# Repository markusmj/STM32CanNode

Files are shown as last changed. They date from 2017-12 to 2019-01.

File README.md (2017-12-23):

# STM32CanNode

Software still highly unstable and updating code all the time. Use at your own risk!!!

Projects goal is to make a simple Can Node which will read 10 analog inputs and send their data to Canbus. Idea is also to design simple connecting PCB where common and cheap STM32F103C8T6 Blue Pill Development Board and MCP2515+TJA1050 Can module can be used to create compact package with Analog/digital ports and Can capabilities.

Some key features of selected hardware:
- Fast SPI bus 18MHz
- 1000kbit/s Can bus
- Fast 12-bit ADC
- 10 analog channels

STM32Duino:
http://www.stm32duino.com/

Used MCP2515 library:
https://github.com/Seeed-Studio/CAN_BUS_Shield

More info on STM32 Development Board Nicknamed Blue Pill:
http://wiki.stm32duino.com/index.php?title=Blue_Pill

MCP 2515 Module used:
https://www.banggood.com/D33-MCP2515-CAN-Bus-Module-TJA1050-Receiver-SPI-Protocol-p-1015302.html

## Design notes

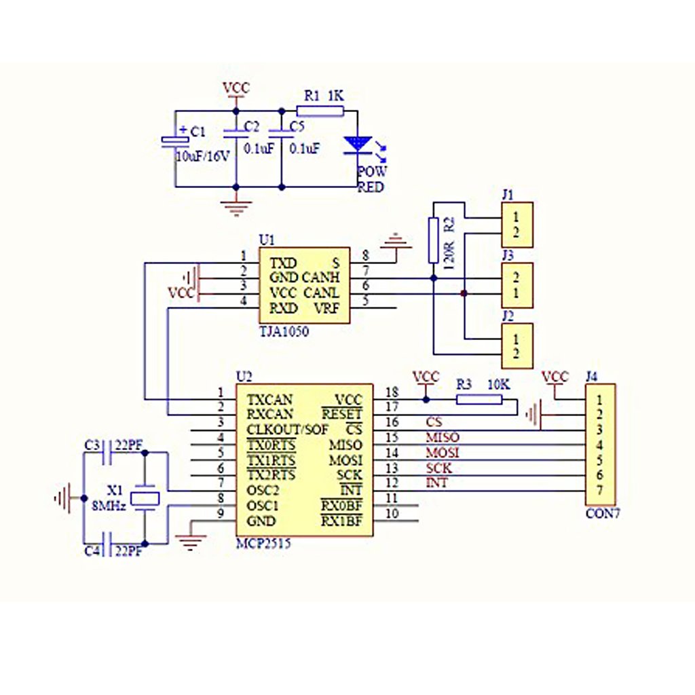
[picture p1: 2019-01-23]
MCP2515Schema/61RsJwa0vkL._SL1024_.jpg

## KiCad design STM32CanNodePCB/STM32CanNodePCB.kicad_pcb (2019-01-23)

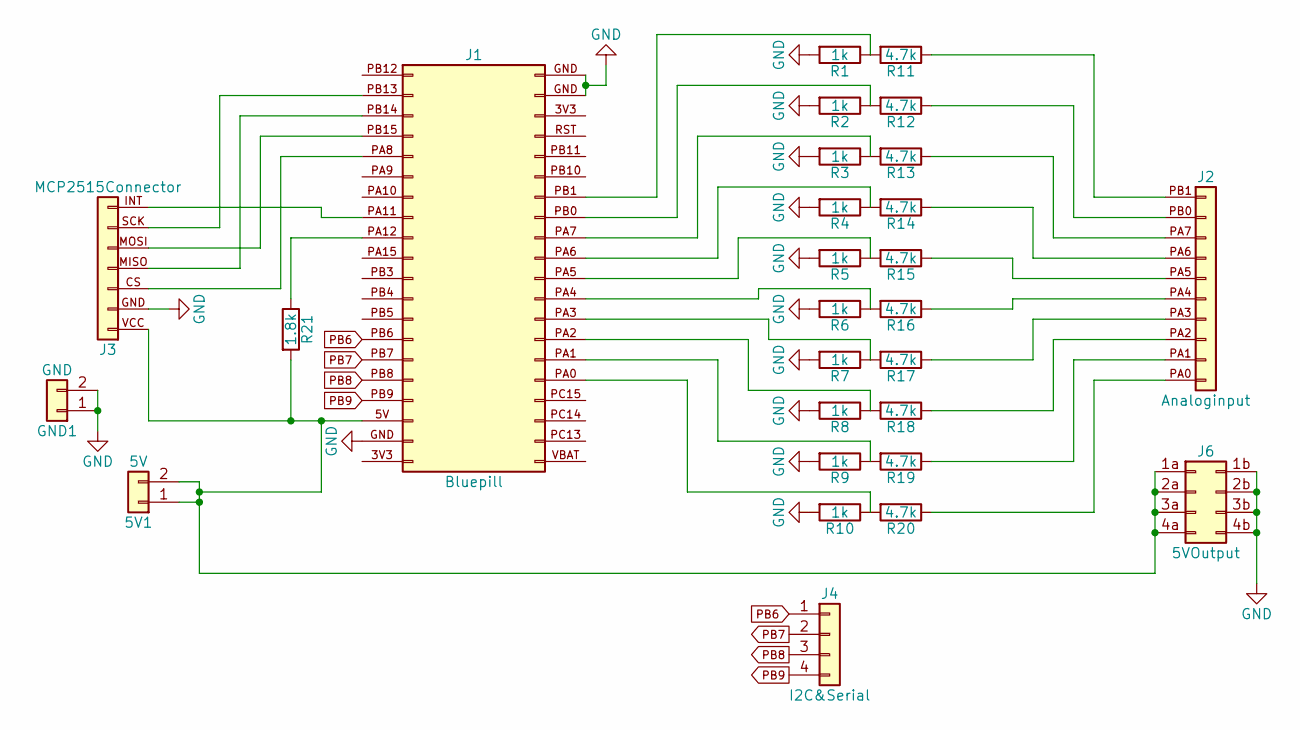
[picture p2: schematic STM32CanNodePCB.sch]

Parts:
5V1: 5V; Pin_Header_Straight_1x02_Pitch2.54mm
GND1: GND; Pin_Header_Straight_1x02_Pitch2.54mm
J1: Bluepill; BluePill
J2: Analoginput
J3: MCP2515Connector
J4: I2C&Serial; Pin_Header_Straight_1x04_Pitch2.54mm
J6: 5VOutput
R1, R2, R3, R4, R5, R6, R7, R8, R9, R10: 1k; R_1206_HandSoldering
R11, R12, R13, R14, R15, R16, R17, R18, R19, R20: 4.7k; R_1206_HandSoldering
R21: 1.8k; R_1206_HandSoldering

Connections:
GND: GND1.1, GND1.2, J1.GND, J3.GND, J6.1b, J6.2b, J6.3b, J6.4b, R1.2, R2.2, R3.2, R4.2, R5.2, R6.2, R7.2, R8.2, R9.2, R10.2
unnamed: 5V1.1, 5V1.2, J1.5V, J3.VCC, J6.1a, J6.2a, J6.3a, J6.4a, R21.2
unnamed: J1.PA0, R10.1, R20.2
unnamed: J1.PA1, R9.1, R19.2
unnamed: J1.PA2, R8.1, R18.2
unnamed: J1.PA3, R7.1, R17.2
unnamed: J1.PA4, R6.1, R16.2
unnamed: J1.PA5, R5.1, R15.2
unnamed: J1.PA6, R4.1, R14.2
unnamed: J1.PA7, R3.1, R13.2
unnamed: J1.PA8, J3.CS
unnamed: J1.PA11, J3.INT
unnamed: J1.PA12, R21.1
unnamed: J1.PB0, R2.1, R12.2
unnamed: J1.PB1, R1.1, R11.2
unnamed: J1.PB13, J3.SCK
unnamed: J1.PB14, J3.MISO
unnamed: J1.PB15, J3.MOSI
unnamed: J2.PA0, R20.1
unnamed: J2.PA1, R19.1
unnamed: J2.PA2, R18.1
unnamed: J2.PA3, R17.1
unnamed: J2.PA4, R16.1
unnamed: J2.PA5, R15.1
unnamed: J2.PA6, R14.1
unnamed: J2.PA7, R13.1
unnamed: J2.PB0, R12.1
unnamed: J2.PB1, R11.1
PB6: J1.PB6, J4.1
PB7: J1.PB7, J4.2
PB8: J1.PB8, J4.3
PB9: J1.PB9, J4.4

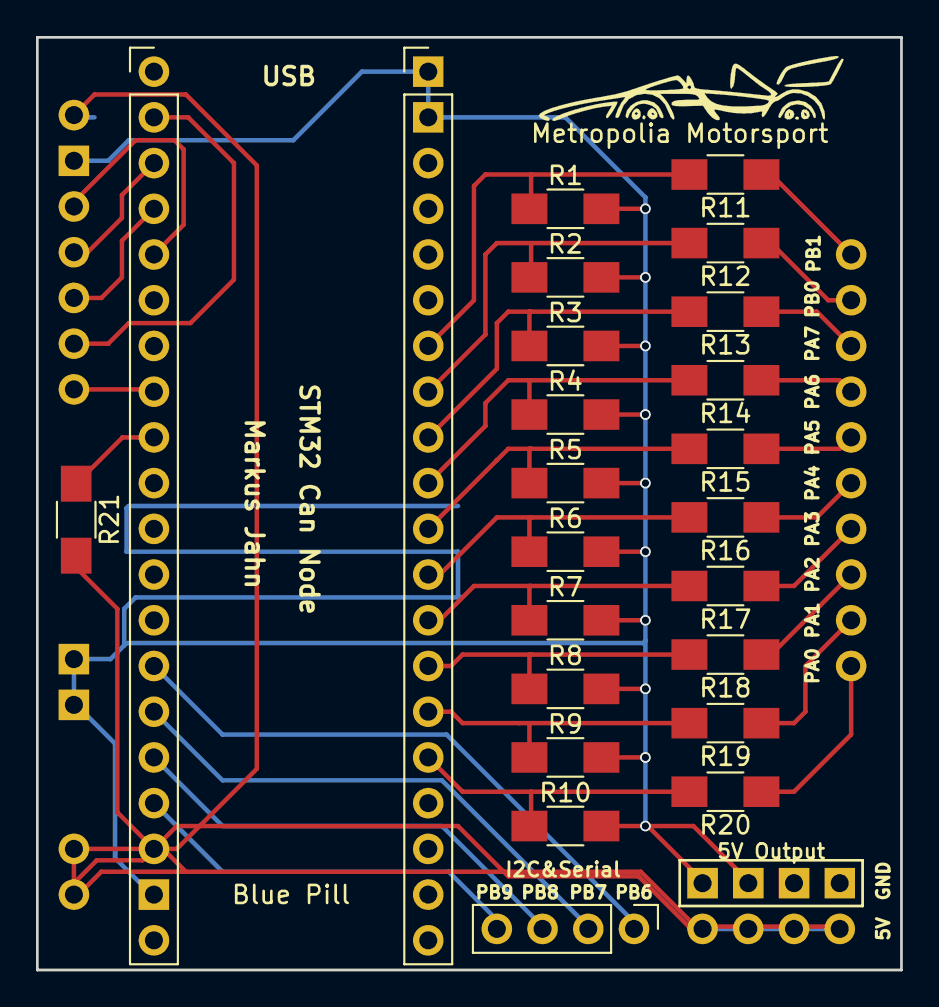
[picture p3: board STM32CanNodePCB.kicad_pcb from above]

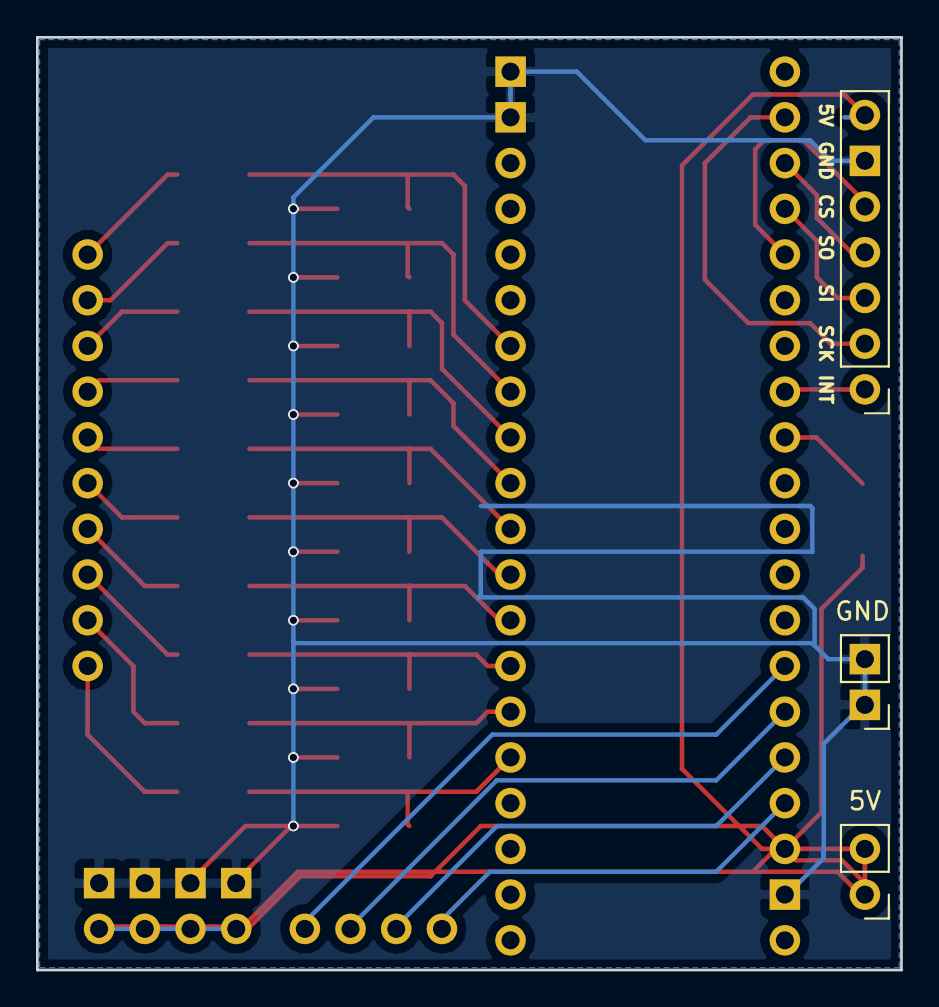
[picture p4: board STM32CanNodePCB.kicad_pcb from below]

Board: 2 copper layers, 48.0 x 51.8 mm, 28 parts (3 on the bottom side), 32 nets.

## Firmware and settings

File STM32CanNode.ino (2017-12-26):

// demo: CAN-BUS Shield, send data
#include <mcp_can.h>
#include <SPI.h>
#include <STM32ADC.h>

/*
 * Pin Connections to MCP2515
 * 
 * PB13 <-> SCK
 * PB14 <-> MISO
 * PB15 <-> MOSI
 * PA8 <-> CS
 * PA11 <-> INT 
 * 5V <-> VCC
 * GND <-> GND
 */

uint8 pins[] = {PA0,PA1,PA2,PA3,PA4,PA5,PA6,PA7,PB0}; //Analog input pins



unsigned char stmp[8] = {0, 0, 0, 0, 0, 0, 0, 0};
unsigned char stmp2[8] = {0, 0, 0, 0, 0, 0, 0, 0};
unsigned char stmp3[8] = {0, 0, 0, 0, 0, 0, 0, 0};

const int SPI_CS_PIN = PA8; //MCP2515 CS pin

const int maxSamples = 9; // 10 Analog inputs
const int avgsamples=5; // How many reads to average for increased accuracy. Max. 15 samples.

//Frequency input data
HardwareTimer pwmtimer(4); //Just for checking
unsigned long freqtime = micros();
unsigned long freq;

// Array for the ADC data
uint16 dataPoints[maxSamples];
uint16 tempdataPoints[maxSamples];


MCP_CAN CAN(SPI_CS_PIN);                                    // Set CS pin

volatile static bool dma1_ch1_Active; //flag for interrupt
STM32ADC NodeADC(ADC1);

void setup()
{

    //PWM write to check frequency reader
    pinMode(PB9,PWM);
    pwmtimer.setPrescaleFactor(1);
    pwmtimer.setPeriod(1000);
    pwmWrite(PB9, 5000);
    
    // Frequency read. Remove/add accordingly to analog inputs.
    pinMode(PB1,INPUT_PULLDOWN);
    attachInterrupt(PB1, interruptFunction, FALLING);
        
    SPI.setModule(2);   //Define SPI to SPI2
    SPI.setClockDivider(SPI_CLOCK_DIV2);   //Define Speed of SPI
    Serial.begin(115200);
    

    while (CAN_OK != CAN.begin(CAN_1000KBPS))              // Init can bus : baudrate = 1000k
    {
        
        Serial.println("CAN BUS Shield init fail");
        Serial.println(" Init CAN BUS Shield again");
        delay(100);
    }
    
    Serial.println("CAN BUS Shield init ok!");

    //calibrate ADC
    NodeADC.calibrate(); 
    NodeADC.setSampleRate(ADC_SMPR_13_5); //sample ratio
    NodeADC.setPins(pins, maxSamples);   //pins to be converted
    NodeADC.setScanMode();               //Set the ADC in Scan Mode
    
}


void loop()
{  
    int Timing = micros();

    for(unsigned int j = 0; j < maxSamples; j++) {tempdataPoints[j] = 0;}  //Zeros to temp variable
    
        for(unsigned int i = 0; i < avgsamples; i++) {                       // --- Read Analog ports 15 times to get average of readings. Remove Lines marked with --- to read faster without averaging
        dma1_ch1_Active = 1;
        NodeADC.setDMA(dataPoints, maxSamples, (DMA_MINC_MODE | DMA_TRNS_CMPLT), DMA1_CH1_Event); 
        NodeADC.startConversion();
        while (dma1_ch1_Active == 1); //wait for DMA to complete.  
              for(unsigned int j = 0; j < maxSamples; j++) {                 // ---
              tempdataPoints[j] = tempdataPoints[j] + dataPoints[j]; // --- Add values to temp variable
              }                                                      // ---
    
        }                                                            // ---

    for(unsigned int i = 0; i < maxSamples; i++) {dataPoints[i] = tempdataPoints [i]/avgsamples;}    // --- Average dataPoints from temp variable.  
    
    unsigned char stmp[8] = {lowByte(dataPoints[0]), highByte(dataPoints[0]), lowByte(dataPoints[1]), highByte(dataPoints[1]), lowByte(dataPoints[2]), highByte(dataPoints[2]), lowByte(dataPoints[3]), highByte(dataPoints[3])};
    unsigned char stmp2[8] = {lowByte(dataPoints[4]), highByte(dataPoints[4]), lowByte(dataPoints[5]), highByte(dataPoints[5]), lowByte(dataPoints[6]), highByte(dataPoints[6]), lowByte(dataPoints[7]), highByte(dataPoints[7])};
    unsigned char stmp3[8] = {lowByte(dataPoints[8]), highByte(dataPoints[8]), lowByte(dataPoints[9]), highByte(dataPoints[9]), 0, 0, 0, 0};

    // Send data:  id = 0x00, standard frame, data len = 8, stmp: data buf
    
    CAN.sendMsgBuf(0x29A,0, 8, stmp);
    CAN.sendMsgBuf(0x666,0, 8, stmp2);
    CAN.sendMsgBuf(0x66,0, 8, stmp3);

    for(unsigned int i = 0; i < maxSamples; i ++) {
      dataPoints[i]=dataPoints[i]*10/124 ;  //map(dataPoints[i], 0, 4095, 0, 330)
    }
    
    
    Timing = micros() - Timing;       //Timing checks how long it takes to make analog reads and send data to canbus       
    Serial.print("ADC+CAN: ");
    Serial.println(Timing);           //Uncomment if needed. Also from loops first line.
    
    for(unsigned int i = 0; i < maxSamples; i ++) {
            Serial.print("Voltage[");
            Serial.print(i);
            Serial.print("] = ");
            Serial.println(dataPoints[i]);
    }
    Serial.print("Freq: ");
    Serial.println(freq);
    delay(100);                        // send data once per 0.1 second
}

static void DMA1_CH1_Event() {
  dma1_ch1_Active = 0;
}

void interruptFunction() {
   freq = 1000000 / (micros()+1 - freqtime);
   freqtime = micros();
}

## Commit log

2017-12-23 Faster ADC Read
2017-12-23 Added pin definitions
2019-01-23 Added Kicad PCB files
    [STM32CanNodePCB-B.Cu.gbl, STM32CanNodePCB-B.Mask.gbs, STM32CanNodePCB-B.SilkS.gbo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]
